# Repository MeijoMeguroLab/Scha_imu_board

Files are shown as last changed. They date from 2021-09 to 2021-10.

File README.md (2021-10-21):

# scha_imu_board

## Overview
This package contains ROS driver nodes for Murata sensor products mainly communicate by SPI(Serial Periferal Interface).

supported devices:

 - SCHA63T Series
 - SCHA600 Series

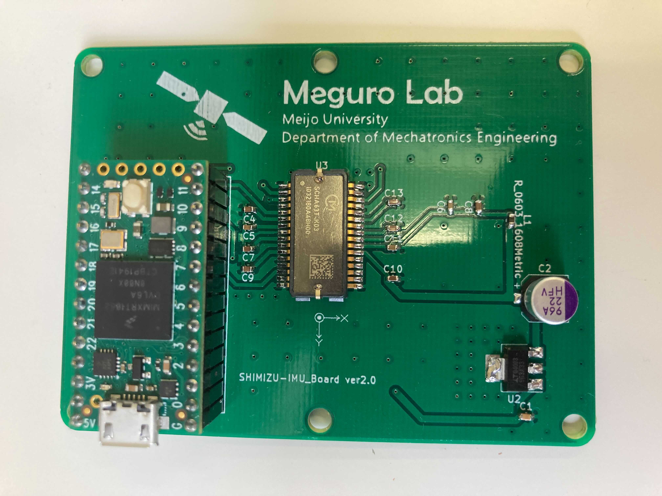
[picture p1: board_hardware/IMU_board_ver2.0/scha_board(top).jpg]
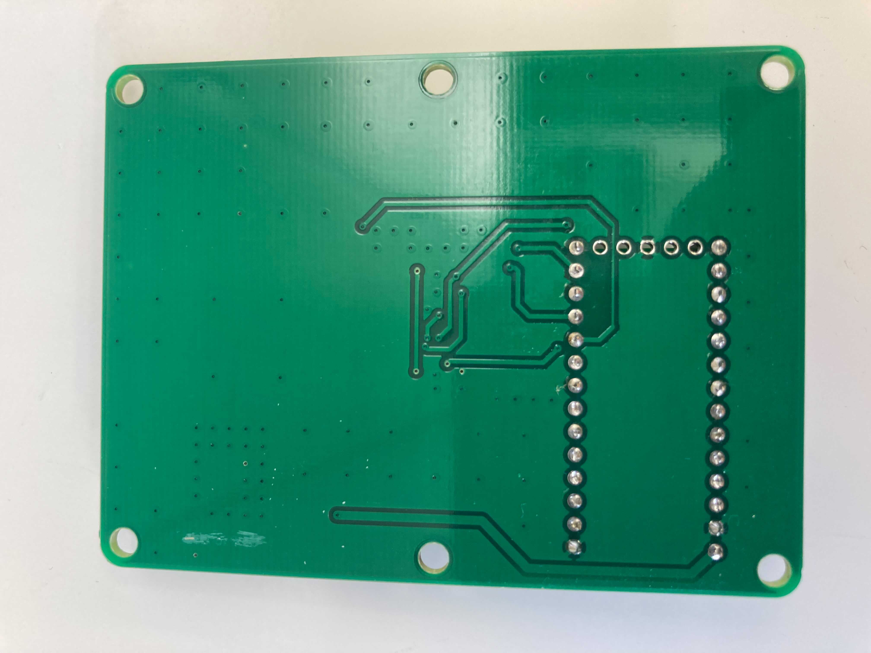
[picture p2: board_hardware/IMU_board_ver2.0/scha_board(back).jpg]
  
 
## Building the Environment

1.
To write software to Teensy4.0, use "Arduino IDE" and "Arduino IDE + Teensyduino".
 Please install them on your Windows PC.
  
2.
  Next, place the extracted folder in an appropriate directory.

"SCHA" ⇒ scha IMU library, place it in the arudino library directory by folder.
                      This is the default location ( C:\Program Files (x86)\Arduino\libraries )
                      e.g.) C:\Program Files (x86)\Arduino\libraries\SCHA
                      
Change the valid definitions in SCHA.cpp depending on the platform you are writing to. 

By default, SCHA6xx_x03 is valid.

<br>
"scha_board" ⇒ teensy's working directory.
                      Place it anywhere you want and run scha_board.ino when compiling/writing.

3.
  After placing the folder, double-click scha_board.ino to run it in Arduino IDE.
  Click the verification button (check mark) in the upper left corner to compile the program.
  
  After the compile result is displayed at the bottom of Arduino IDE with no error, click
  Press the Write button on Teensy4.0 once.
  (Teensy 4.0 will restart automatically after writing.)
  
4.
  "Click the Terminal button in the upper right corner of the Arduino IDE to confirm that the data acquisition is successful.

## How to use

The topic name and .yaml file name are "series name"_xxx, so please change them as necessary.
There is no problem if you use them as they are.

1.
 "ros_package/scha_imu_driver" is a ros driver that runs on linux.
 Please install the ros environment on your Linux PC.

2.
Place "ros_package/scha_imu_driver" in any workspace and build it.

3.
Connect the device to your PC, and edit the device in the .yaml file in "ros_package/scha_imu_driver/config" according to the connection status.

4.
Run the appropriate launch for your device from "ros_package/scha_imu_driver/launch".

## License
scha_imu_board is provided under the BSD 3-Clause License.

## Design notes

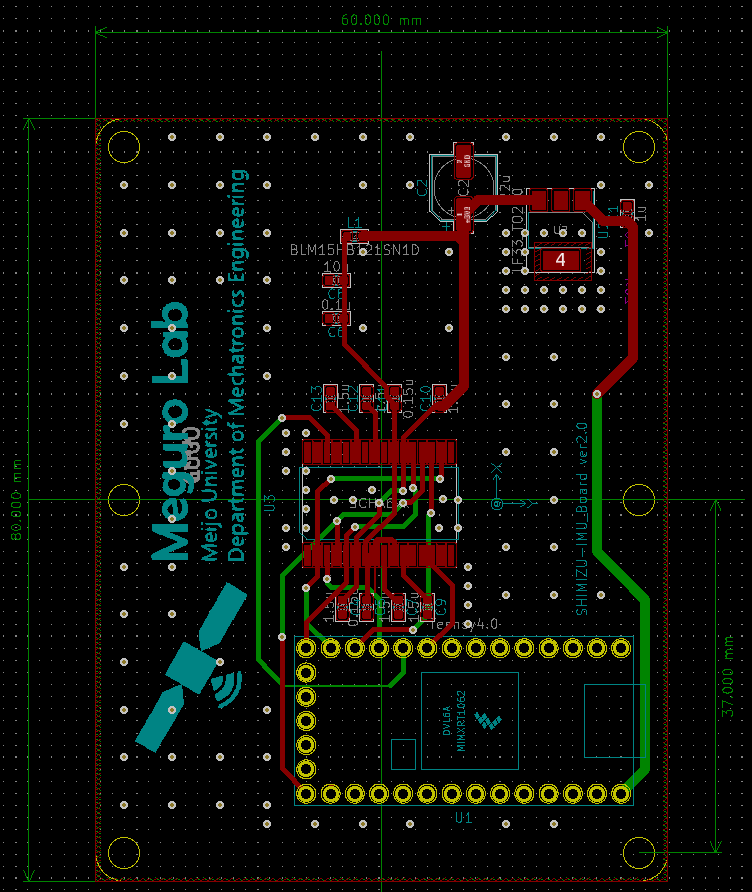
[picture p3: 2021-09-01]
board_hardware/IMU_board_ver2.0/pcb.png

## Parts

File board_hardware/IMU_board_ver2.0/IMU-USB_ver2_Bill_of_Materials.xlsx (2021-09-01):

IMU_board Bill of Materials
No. | value | Unit price[yen] | Quantity(1set) | Purchase unit quantity | URL
C6 | 0.1u | 100 | 1 | 40 | https://akizukidenshi.com/catalog/g/gP-13374/
C5,C11 | 0.15u | 42.26 | 2 | 1 | https://www.marutsu.co.jp/pc/i/26774335/
C1 | 1.0u | 100 | 1 | 20 | https://akizukidenshi.com/catalog/g/gP-14526/
C4,C7,C9,C10,C12,C13 | 1.5u | 67.32 | 6 | 1 | https://www.marutsu.co.jp/pc/i/27066708/
C8 | 10u | 150 | 1 | 10 | https://akizukidenshi.com/catalog/g/gP-13161/
C2 | 22u | 60 | 1 | 1 | https://akizukidenshi.com/catalog/g/gP-14491/
L1 | BLM18RK121SN1D | 100 | 1 | 25 | https://akizukidenshi.com/catalog/g/gP-04445/
U1 | (Teensy4.0) | 3092 | 1 | 1 | https://www.switch-science.com/catalog/5877/
 | (pin header) | 35 | 28 | 40 | https://akizukidenshi.com/catalog/g/gC-00167/
U2 | LT1963AEST-3.3 | 350 | 1 | 1 | https://akizukidenshi.com/catalog/g/gI-16060/
U3 | SCHA6xx(murata_IMU)
 | ピンソケット | 80 | 28 | 42 | https://akizukidenshi.com/catalog/g/gC-05779/
whithout pin header | (Teensy4.0) | 3092 | 1 | 1 | https://www.switch-science.com/catalog/5877/
 | (pin header) | 35 | 28 | 40 | https://akizukidenshi.com/catalog/g/gC-00167/
with pin header | Teensy4.0(whith pin header) | 3442 | 1 | 1 | https://www.switch-science.com/catalog/6570/

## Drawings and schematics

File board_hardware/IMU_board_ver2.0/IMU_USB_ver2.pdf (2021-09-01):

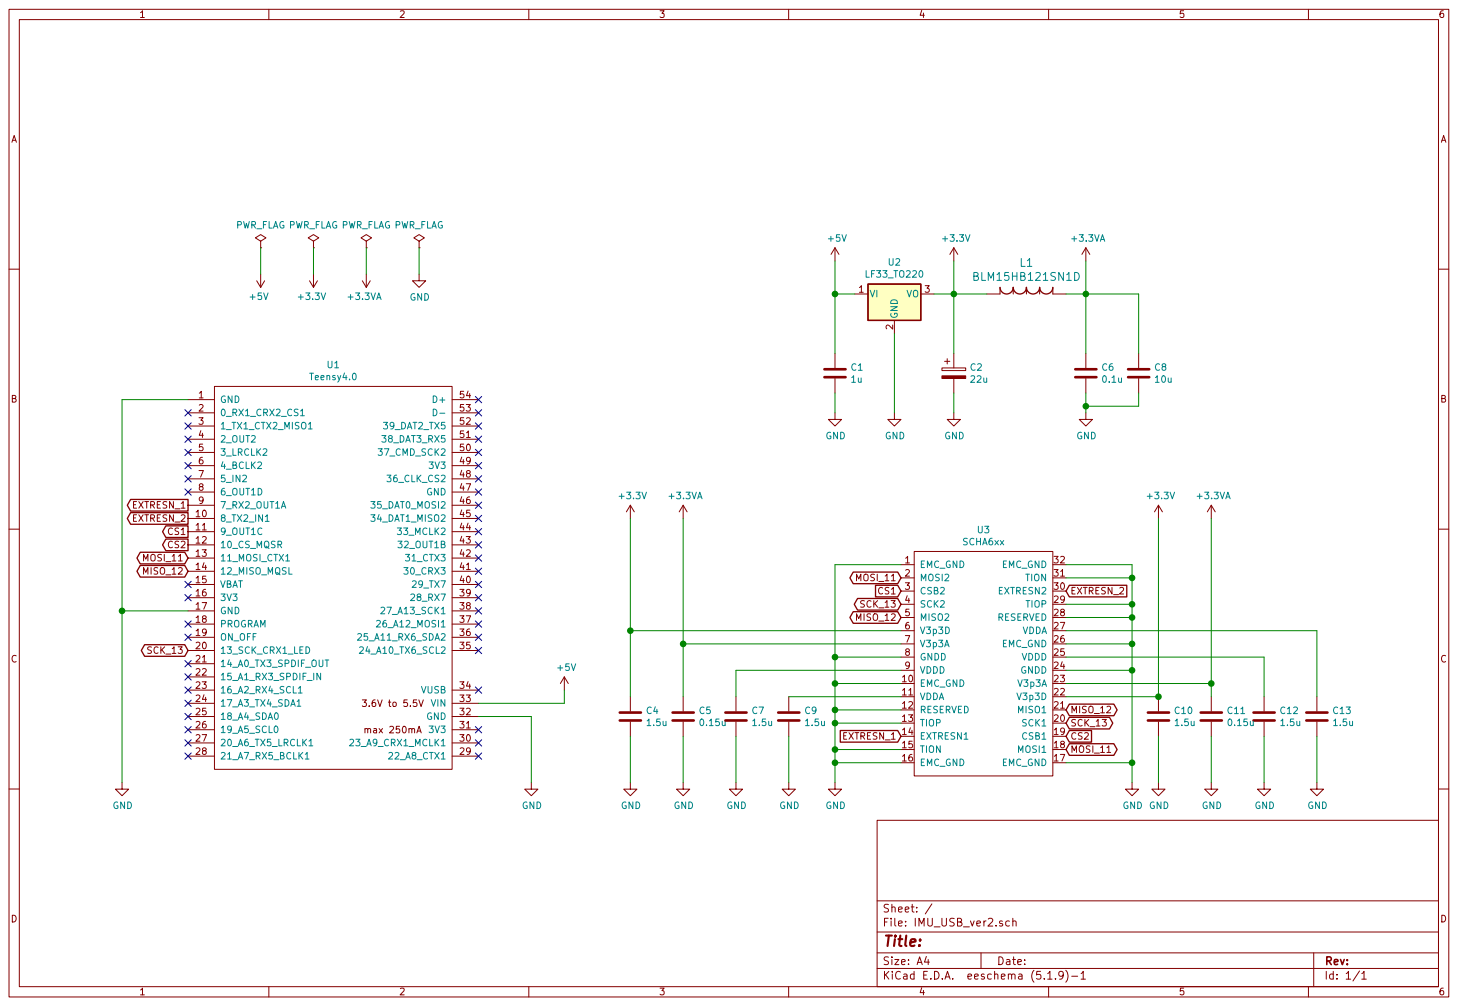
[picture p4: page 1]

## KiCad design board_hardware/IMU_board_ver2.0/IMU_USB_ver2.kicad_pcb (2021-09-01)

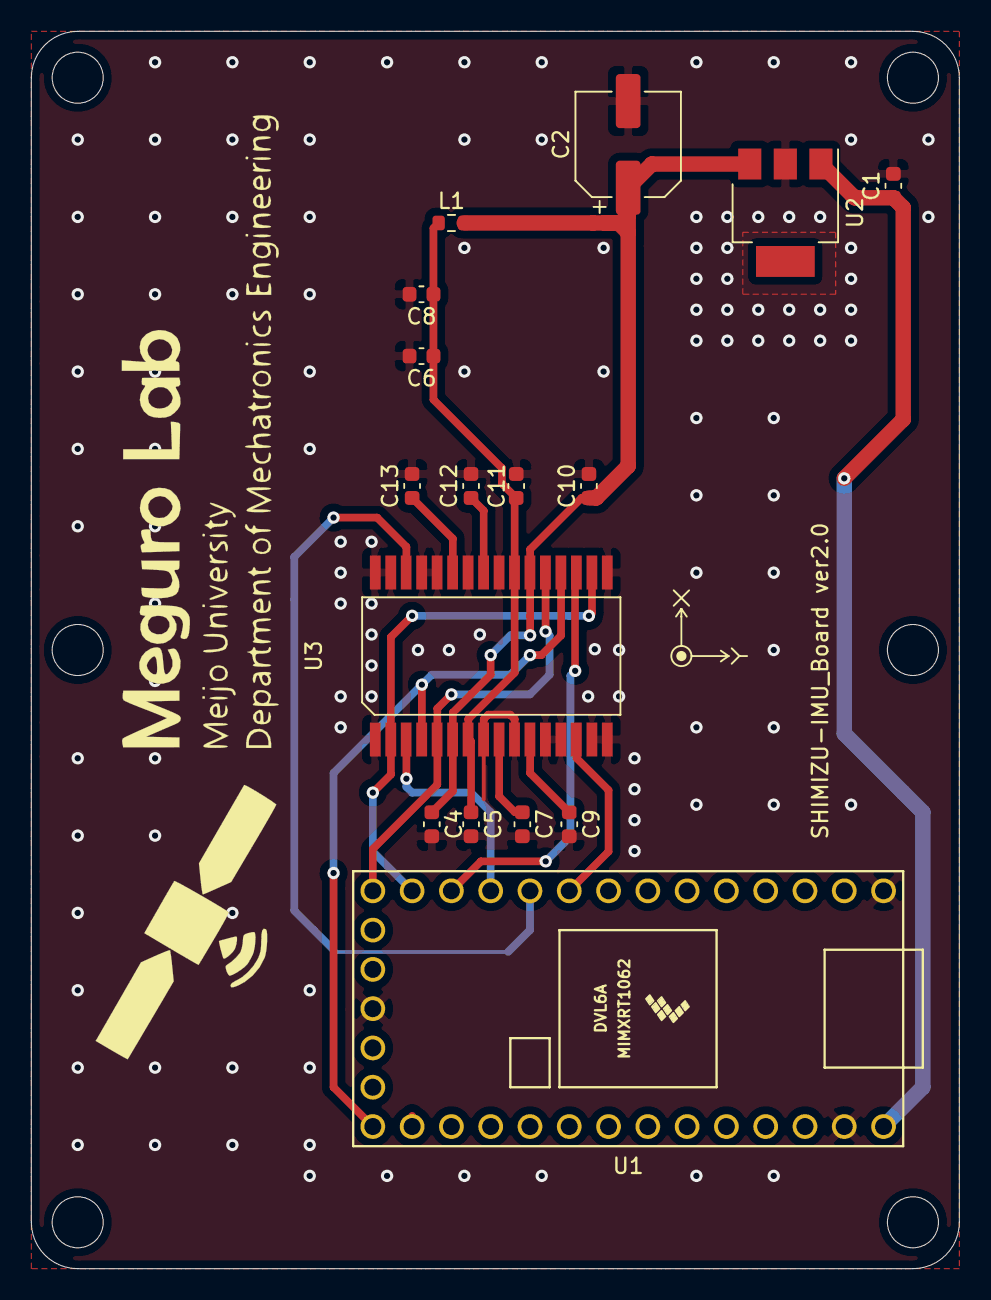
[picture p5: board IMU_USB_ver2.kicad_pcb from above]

Board: 2 copper layers, 60.0 x 80.0 mm, 16 parts (0 on the bottom side), 15 nets.

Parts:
C1: 1u; C_0603_1608Metric
C2: 22u; CP_Elec_6.3x5.9
C4, C7, C9, C10, C12, C13: 1.5u; C_0603_1608Metric
C5, C11: 0.15u; C_0603_1608Metric
C6: 0.1u; C_0603_1608Metric
C8: 10u; C_0603_1608Metric
L1: BLM15HB121SN1D
U1: Teensy4.0; Teensy40_2
U2: LF33_TO220; SOT-223
U3: SCHA6xx

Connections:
+3.3VA: C5.1, C6.1, C8.1, C11.1, L1.1, U3.7, U3.23
+3V3: C2.1, C4.1, C10.1, L1.2, U2.3, U3.6, U3.22
+5V: C1.1, U1.33, U2.1
CS1: U1.11, U3.3
CS2: U1.12, U3.19
EXTRESN_1: U1.9, U3.14
EXTRESN_2: U1.10, U3.30
GND: C1.2, C2.2, C4.2, C5.2, C6.2, C7.2, C8.2, C9.2, C10.2, C11.2, C12.2, C13.2, U1.1, U1.17, U1.32, U2.2, U3.1, U3.8, U3.10, U3.12, U3.13, U3.15, U3.16, U3.17, U3.24, U3.26, U3.28, U3.29, U3.31, U3.32
MISO_12: U1.14, U3.5, U3.21
MOSI_11: U1.13, U3.2, U3.18
unnamed: C7.1, U3.9
unnamed: C9.1, U3.11
unnamed: C12.1, U3.25
unnamed: C13.1, U3.27
SCK_13: U1.20, U3.4, U3.20

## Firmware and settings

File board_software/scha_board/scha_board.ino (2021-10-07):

// Copyright (c) 2021, MeijoMeguroLab
// All rights reserved.
//
// This software is based in part on the source code available for download from
// https://www.murata.com/ja-jp/products/sensor/gyro/overview/lineup/scha63t/form
// The copyright of the quoted material is held by Murata Electronics Oy.
//
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
// THIS SOFTWARE IS PROVIDED BY THE COPYRIGHT HOLDERS AND CONTRIBUTORS "AS IS" AND
// ANY EXPRESS OR IMPLIED WARRANTIES, INCLUDING, BUT NOT LIMITED TO, THE IMPLIED
// WARRANTIES OF MERCHANTABILITY AND FITNESS FOR A PARTICULAR PURPOSE ARE
// DISCLAIMED. IN NO EVENT SHALL COPYRIGHT HOLDER BE LIABLE FOR ANY
// DIRECT, INDIRECT, INCIDENTAL, SPECIAL, EXEMPLARY, OR CONSEQUENTIAL DAMAGES
// (INCLUDING, BUT NOT LIMITED TO, PROCUREMENT OF SUBSTITUTE GOODS OR SERVICES;
// LOSS OF USE, DATA, OR PROFITS; OR BUSINESS INTERRUPTION) HOWEVER CAUSED AND
// ON ANY THEORY OF LIABILITY, WHETHER IN CONTRACT, STRICT LIABILITY, OR TORT
// (INCLUDING NEGLIGENCE OR OTHERWISE) ARISING IN ANY WAY OUT OF THE USE OF THIS
// SOFTWARE, EVEN IF ADVISED OF THE POSSIBILITY OF SUCH DAMAGE.


#include <SCHA.h>
#include <SPI.h>
#include "USBHost_t36.h"
#include <math.h>

#define USBBAUD       230400
#define IMU_BUFF_SIZE 33

#define interval_value   20 /* IMU polling Interval value (ms) */

#define DEBUG_FLAG 0

// ---- IMU ----
SCHA6xx IMU(9, 10, 8, 7);

unsigned long prev;
int isReceived = 0;
int16_t imu_data[14];

// ---- General ----
unsigned char imu_buff[ IMU_BUFF_SIZE ];
uint8_t sendbuff[ 256 ];

// ---- ---- ----


void sensorRead() {

  FourByte data_tmp;
  data_tmp.bit16[0]=0;data_tmp.bit16[1]=0;
  IMU.available();

  data_tmp.flt = IMU.out_data.gyro_x;
  imu_data[0] = (data_tmp.bit32>>16)&0xFFFF;
  imu_data[1] = (data_tmp.bit32)&0xFFFF;
  data_tmp.flt = IMU.out_data.gyro_y;
  imu_data[2] = (data_tmp.bit32>>16)&0xFFFF;
  imu_data[3] = (data_tmp.bit32)&0xFFFF;
  data_tmp.flt = IMU.out_data.gyro_z;
  imu_data[4] = (data_tmp.bit32>>16)&0xFFFF;
  imu_data[5] = (data_tmp.bit32)&0xFFFF;

  data_tmp.flt = IMU.out_data.acc_x;
  imu_data[6] = (data_tmp.bit32>>16)&0xFFFF;
  imu_data[7] = (data_tmp.bit32)&0xFFFF;
  data_tmp.flt = IMU.out_data.acc_y;
  imu_data[8] = (data_tmp.bit32>>16)&0xFFFF;
  imu_data[9] = (data_tmp.bit32)&0xFFFF;
  data_tmp.flt = IMU.out_data.acc_z;
  imu_data[10] = (data_tmp.bit32>>16)&0xFFFF;
  imu_data[11] = (data_tmp.bit32)&0xFFFF;

  data_tmp.flt = IMU.out_data.temp_due;
  imu_data[12] = (data_tmp.bit32>>16)&0xFFFF;
  imu_data[13] = (data_tmp.bit32)&0xFFFF;
}


void setup() {

  while (!Serial) ;
  Serial.begin(USBBAUD);
  
  delay(2000);
  if(IMU.begin() == false) {
    Serial.println("Murata SCHA6xx not connected.");
    while(1); //Freeze
  }
  delay(10);

  memset(sendbuff, 0x00, 256);
  memset(imu_data, 0x00, 14);
}

void loop() {

  int send_length;
  unsigned long curr = millis();
  if ((curr - prev) >= interval_value) {
    sensorRead();
    isReceived = 1;
    prev = curr;

    imu_buff[0] = 0x49; // 'I' hex = 0x49
    imu_buff[1] = (curr >> 24)&0xFF; // Timestap [1]-[4]
    imu_buff[2] = (curr >> 16)&0xFF;
    imu_buff[3] = (curr >> 8)&0xFF;
    imu_buff[4] = (curr)&0xFF;
    // Gyro
    imu_buff[5] = (imu_data[0]>>8)&0xFF;
    imu_buff[6] = (imu_data[0])&0xFF;
    imu_buff[7] = (imu_data[1]>>8)&0xFF;
    imu_buff[8] = (imu_data[1])&0xFF;
    imu_buff[9] = (imu_data[2]>>8)&0xFF;
    imu_buff[10] = (imu_data[2])&0xFF;
    imu_buff[11] = (imu_data[3]>>8)&0xFF;
    imu_buff[12] = (imu_data[3])&0xFF;
    imu_buff[13] = (imu_data[4]>>8)&0xFF;
    imu_buff[14] = (imu_data[4])&0xFF;
    imu_buff[15] = (imu_data[5]>>8)&0xFF;
    imu_buff[16] = (imu_data[5])&0xFF;
    // Accl
    imu_buff[17] = (imu_data[6]>>8)&0xFF;
    imu_buff[18] = (imu_data[6])&0xFF;
    imu_buff[19] = (imu_data[7]>>8)&0xFF;
    imu_buff[20] = (imu_data[7])&0xFF;
    imu_buff[21] = (imu_data[8]>>8)&0xFF;
    imu_buff[22] = (imu_data[8])&0xFF;
    imu_buff[23] = (imu_data[9]>>8)&0xFF;
    imu_buff[24] = (imu_data[9])&0xFF;
    imu_buff[25] = (imu_data[10]>>8)&0xFF;
    imu_buff[26] = (imu_data[10])&0xFF;
    imu_buff[27] = (imu_data[11]>>8)&0xFF;
    imu_buff[28] = (imu_data[11])&0xFF;
    //TEMP
    imu_buff[29] = (imu_data[12]>>8)&0xFF;
    imu_buff[30] = (imu_data[12])&0xFF;
    imu_buff[31] = (imu_data[13]>>8)&0xFF;
    imu_buff[32] = (imu_data[13])&0xFF;
  }

  if(isReceived == 1) {
    /* Set Header Data */
    sendbuff[0] = 0xF7;
    sendbuff[1] = 0xE0;
    send_length = 2;
    
    // Set IMU Data
    memcpy(&sendbuff[send_length], imu_buff, IMU_BUFF_SIZE);
    send_length += IMU_BUFF_SIZE;
    isReceived = 0;

#if DEBUG_FLAG
    Serial.printf("ACC(X,Y,Z):%+.3f,%+.3f,%+.3f[g] GYRO(X,Y,Z):%+.3f,%+.3f,%+.3f[dps]\n", 
        IMU.out_data.acc_x, IMU.out_data.acc_y,IMU.out_data.acc_z, 
        IMU.out_data.gyro_x,IMU.out_data.gyro_y, IMU.out_data.gyro_z);

#else
    Serial.write((byte*)sendbuff, send_length);
    memset(sendbuff, 0x00, send_length);
#endif

  }

}

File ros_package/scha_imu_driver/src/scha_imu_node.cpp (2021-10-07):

// Copyright (c) 2021, MeijoMeguroLab
// All rights reserved.
//
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
// THIS SOFTWARE IS PROVIDED BY THE COPYRIGHT HOLDERS AND CONTRIBUTORS "AS IS" AND
// ANY EXPRESS OR IMPLIED WARRANTIES, INCLUDING, BUT NOT LIMITED TO, THE IMPLIED
// WARRANTIES OF MERCHANTABILITY AND FITNESS FOR A PARTICULAR PURPOSE ARE
// DISCLAIMED. IN NO EVENT SHALL COPYRIGHT HOLDER BE LIABLE FOR ANY
// DIRECT, INDIRECT, INCIDENTAL, SPECIAL, EXEMPLARY, OR CONSEQUENTIAL DAMAGES
// (INCLUDING, BUT NOT LIMITED TO, PROCUREMENT OF SUBSTITUTE GOODS OR SERVICES;
// LOSS OF USE, DATA, OR PROFITS; OR BUSINESS INTERRUPTION) HOWEVER CAUSED AND
// ON ANY THEORY OF LIABILITY, WHETHER IN CONTRACT, STRICT LIABILITY, OR TORT
// (INCLUDING NEGLIGENCE OR OTHERWISE) ARISING IN ANY WAY OUT OF THE USE OF THIS
// SOFTWARE, EVEN IF ADVISED OF THE POSSIBILITY OF SUCH DAMAGE.

#include "ros/ros.h"
#include "sensor_msgs/Imu.h"
#include "std_msgs/Float64.h"
#include <math.h>
#include <stdio.h>
#include <stdlib.h>
#include <sys/stat.h>
#include <fcntl.h>
#include <sys/types.h>
#include <unistd.h>
#include <stdint.h>
#include <string>
#include <termios.h>
#include <sys/socket.h>
#include <linux/serial.h>
#include <sys/ioctl.h>
#include <unistd.h>

#define GNSS_PACKECT_LEN 2
#define CMD_NUM_MAX (79)
#define BUFF_SIZE 1024

#ifndef SI
#define SI 9.80665
#endif

union FourByte {
    float         flt;
    unsigned long bit32;
    unsigned int bit16[2];
    unsigned char bit8[4];
};

uint32_t imu_time;
// Gyro sensor(x, y, z)
double imu_gyro[3];
// Acceleration sensor(x, y, z)
double imu_accl[3];
// Temperature sensor
double imu_temp;

unsigned char recv_buff[BUFF_SIZE] = {0};
unsigned char buff[BUFF_SIZE] = {0};

void parseIMUdata( unsigned char* imu_data ){

  FourByte data_tmp;
  float local_imu_gyro[3], local_imu_accl[3], local_temp;

  // gyro_x
  data_tmp.bit32 = (*(imu_data+5) << 24) | (*(imu_data+6) << 16 ) | (*(imu_data+7) << 8) | (*(imu_data+8));
  local_imu_gyro[0] = data_tmp.flt;
  
  // gyro_y
  data_tmp.bit32 = (*(imu_data+9) << 24) | (*(imu_data+10) << 16 ) | (*(imu_data+11) << 8) | (*(imu_data+12));
  local_imu_gyro[1] = data_tmp.flt;
  
  // gyro_z
  data_tmp.bit32 = (*(imu_data+13) << 24) | (*(imu_data+14) << 16 ) | (*(imu_data+15) << 8) | (*(imu_data+16));
  local_imu_gyro[2] = data_tmp.flt;
  
  // accl_x
  data_tmp.bit32 = (*(imu_data+17) << 24) | (*(imu_data+18) << 16 ) | (*(imu_data+19) << 8) | (*(imu_data+20));
  local_imu_accl[0] = data_tmp.flt;
  
  // accl_y
  data_tmp.bit32 = (*(imu_data+21) << 24) | (*(imu_data+22) << 16 ) | (*(imu_data+23) << 8) | (*(imu_data+24));
  local_imu_accl[1] = data_tmp.flt;
  
  // accl_z
  data_tmp.bit32 = (*(imu_data+25) << 24) | (*(imu_data+26) << 16 ) | (*(imu_data+27) << 8) | (*(imu_data+28));
  local_imu_accl[2] = data_tmp.flt;

  // temperature
  data_tmp.bit32 = (*(imu_data+29) << 24) | (*(imu_data+30) << 16 ) | (*(imu_data+31) << 8) | (*(imu_data+32));
  local_temp = data_tmp.flt;

  // 32bit convert
  for (int i=0; i < 3; i++)
  {
    /* scha6xx */
    imu_gyro[i] = (double)(local_imu_gyro[i] * (M_PI/180));
    imu_accl[i] = (double)(local_imu_accl[i] * SI);
  }
  
  imu_temp = (double)local_temp;
}

class logger
{
public:

  //! File descripter for USB-ISS
  int fd_;
  //! Saved terminal config
  struct termios defaults_;

  logger()
  {
    imu_gyro[0] = 0.0;
    imu_gyro[1] = 0.0;
    imu_gyro[2] = 0.0;

    imu_accl[0] = 0.0;
    imu_accl[1] = 0.0;
    imu_accl[2] = 0.0;
  }

  ~logger()
  {

  }

  /**
   * @brief Open device
   * @param device Device file name (/dev/ttyACM*)
   * @retval 0 Success
   * @retval -1 Failure
   */
  int open_serial(const char *device_name){
    fd_=open(device_name, O_RDWR | O_NOCTTY | O_NONBLOCK);
    if( -1 == fd_ ){
      perror("open");
      return fd_;
    }

    fcntl(fd_, F_SETFL,0);
    //load configuration
    struct termios conf_tio;
    tcgetattr(fd_,&conf_tio);
    //set baudrate
    speed_t BAUDRATE = B230400;
    cfsetispeed(&conf_tio, BAUDRATE);
    cfsetospeed(&conf_tio, BAUDRATE);
    //non canonical, non echo back
    conf_tio.c_lflag &= ~(ECHO | ICANON);
    //non blocking
    conf_tio.c_cc[VMIN]=0;
    conf_tio.c_cc[VTIME]=0;
    //store configuration

    cfmakeraw(&conf_tio);
    tcsetattr(fd_,TCSANOW,&conf_tio);

    struct serial_struct serial_setting;
    ioctl(fd_, TIOCGSERIAL, &serial_setting);
    serial_setting.flags |= ASYNC_LOW_LATENCY;
    ioctl(fd_, TIOCGSERIAL, &serial_setting);

    return fd_;
  }

  /**
   * @brief Close device
   */
  void closePort()
  {
    if (tcsetattr(fd_, TCSANOW, &defaults_) < 0)
    {
      perror("closePort");
    }
    close(fd_);
  }
};
/* ------------------------------------------------------- */
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
